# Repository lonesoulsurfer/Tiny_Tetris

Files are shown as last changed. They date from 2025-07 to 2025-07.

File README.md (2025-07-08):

# Tiny_Tetris



YouTube Vid
https://www.youtube.com/watch?v=bwNg85aia90&feature=youtu.be

Ever wanted a pocket sized Tetris that you could whip out anytime you wanted?  Well you are in luck.  This build usues an ATTiny85 to run Tetris on an OLED SDD1306 screen.  It's tiny but definitely usable and did I mention it's ridiculously fun to play!

You'll find all of the files in this repository to build your own

I've also done a step by step guide on Instructables in case you are new to this type of thing.  It's takes you through the build and programming the ATTiny85

Instructables - How to program an ATtiny85 & ATtiny13a
https://www.instructables.com/Tiny-Tetris-ATtiny85-Project/

Instructables - ATtiny 85/13 Programmer
https://www.instructables.com/Programmer-for-ATtiny-85/

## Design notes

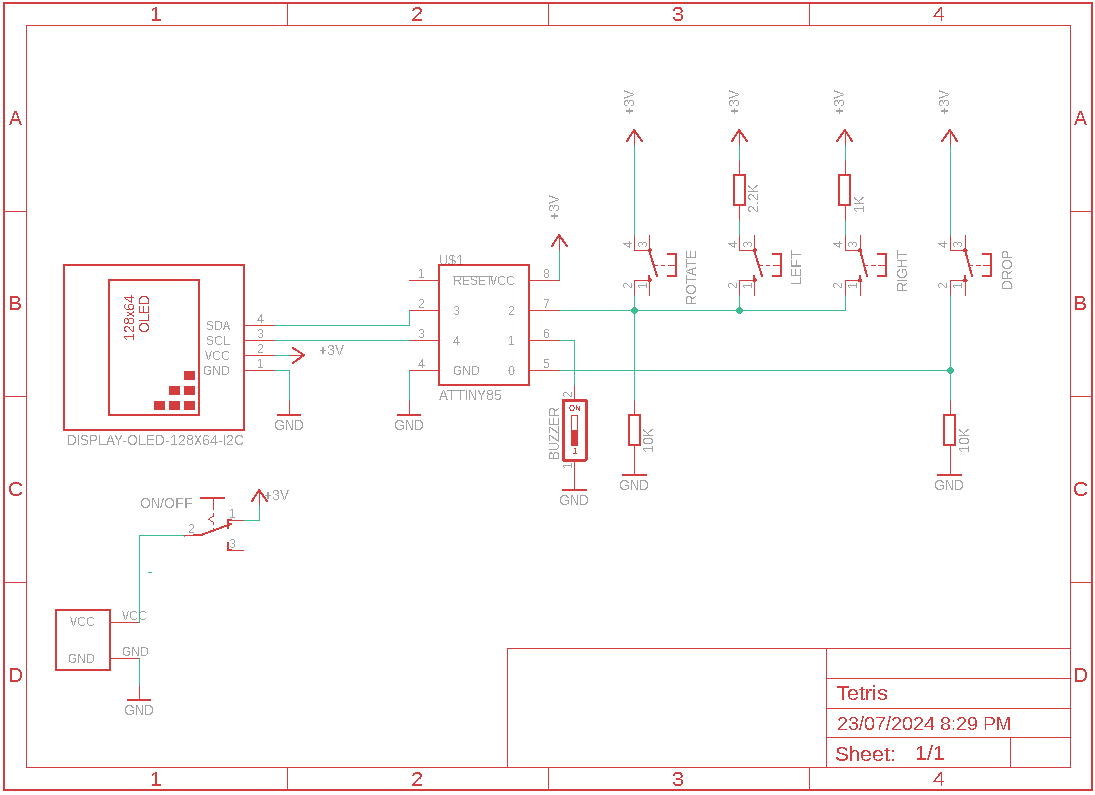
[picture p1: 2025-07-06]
Schematic.png

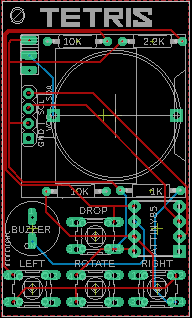
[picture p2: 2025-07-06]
Board.png

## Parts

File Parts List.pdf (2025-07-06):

Part Type Value Qty Link | Image

ATtiny85 IC 1 Link (https://www.aliexpress.com/w/wholesale-attiny-85.html?spm=a2g0o.home.search.0)

Buzzer Passive 1 Link (https://vi.aliexpress.com/item/1005001482792890.html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)

OLED Screen SSD1306 1 Link (https://www.aliexpress.com/w/wholesale-ssd1306.html)

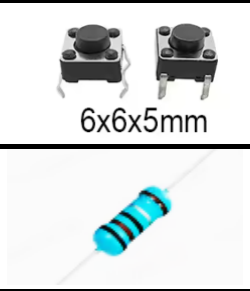
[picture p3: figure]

Mometary Switch Tactile (5mm) 4 Link (https://vi.aliexpress.com/w/wholesale-momentary-tactile-switch.html?spm=a2g0o.productlist.search.0)

10K 2 Resistors Metal Film 1% 1K 1 Link (https://vi.aliexpress.com/w/wholesale-metal-film-1%25-resistor.html?spm=a2g0o.productlist.search.0) 2.2K 1

Battery Holder CR2032 1 Link (https://vi.aliexpress.com/item/4001240194584.html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)

Battery CR2032 Link (https://vi.aliexpress.com/w/wholesale-cr2032-battery.html?spm=a2g0o.productlist.search.0)

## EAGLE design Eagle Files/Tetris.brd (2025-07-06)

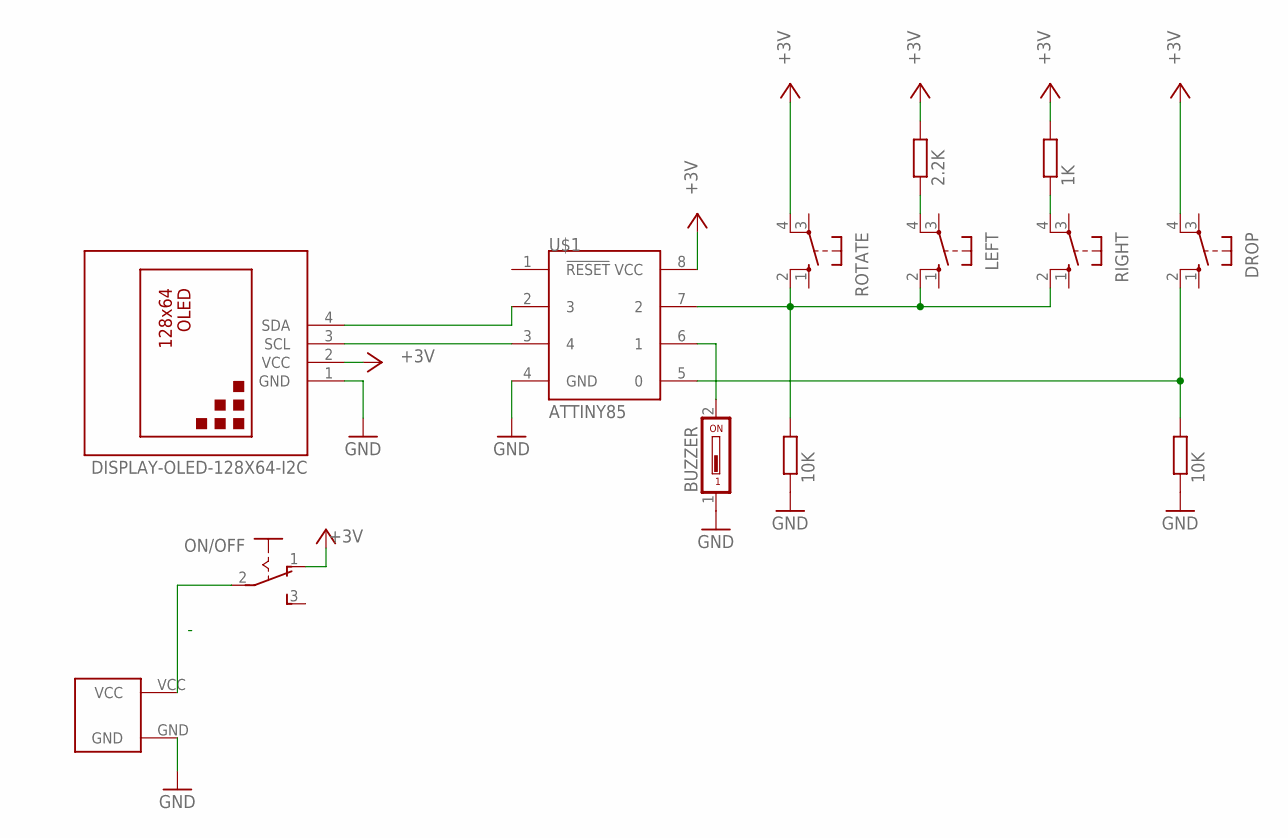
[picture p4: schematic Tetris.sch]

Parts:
BUZZER: DS01; DS-01
DROP: 10-XX; B3F-10XX
LEFT: 10-XX; B3F-10XX
ON/OFF: M251
R1: 2.2K; 0207/10
R2, R4: 10K; 0207/10
R3: 1K; 0207/10
RIGHT: 10-XX; B3F-10XX
ROTATE: 10-XX; B3F-10XX
U$1: ATTINY85; 8P3
U$2: DISPLAY-OLED-128X64-I2C
U$5: CR2032; CR2032-20MM

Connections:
+3V3: DROP.4 (P1), ON/OFF.1 (O), R1.2, R3.2, ROTATE.4 (P1), U$1.8 (VCC), U$2.2 (VCC)
GND: BUZZER.1, R2.1, R4.1, U$1.4 (GND), U$2.1 (GND), U$5.GND
unnamed: U$1.3 (4), U$2.3 (SCL)
unnamed: U$1.2 (3), U$2.4 (SDA)
unnamed: LEFT.4 (P1), R1.1
unnamed: DROP.2 (S1), R2.2, U$1.5 (0)
unnamed: BUZZER.2, U$1.6 (1)
unnamed: R3.1, RIGHT.4 (P1)
unnamed: LEFT.2 (S1), R4.2, RIGHT.2 (S1), ROTATE.2 (S1), U$1.7 (2)
unnamed: ON/OFF.2, U$5.VCC

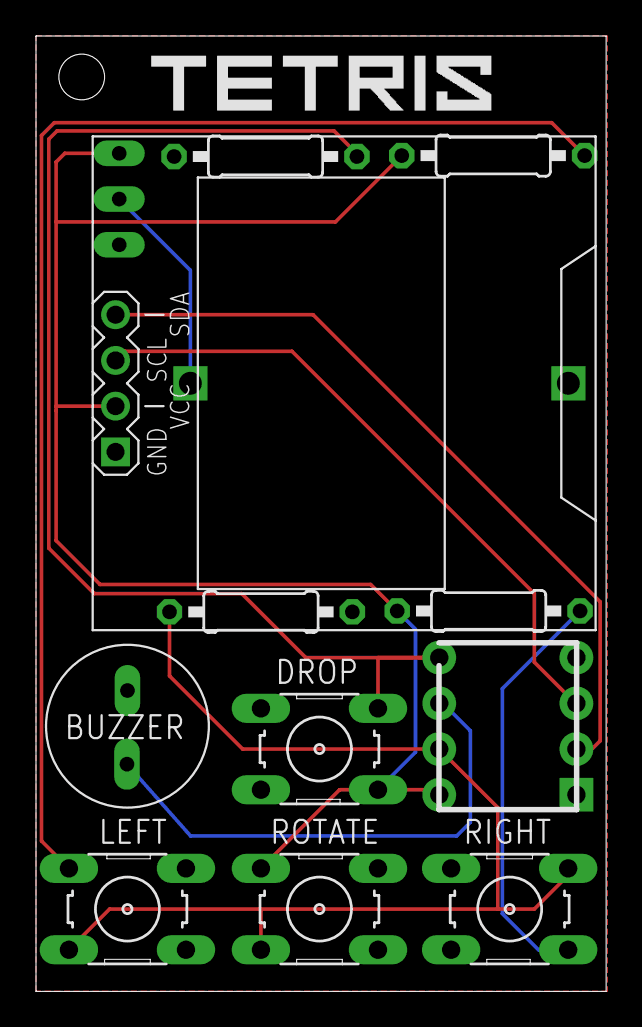
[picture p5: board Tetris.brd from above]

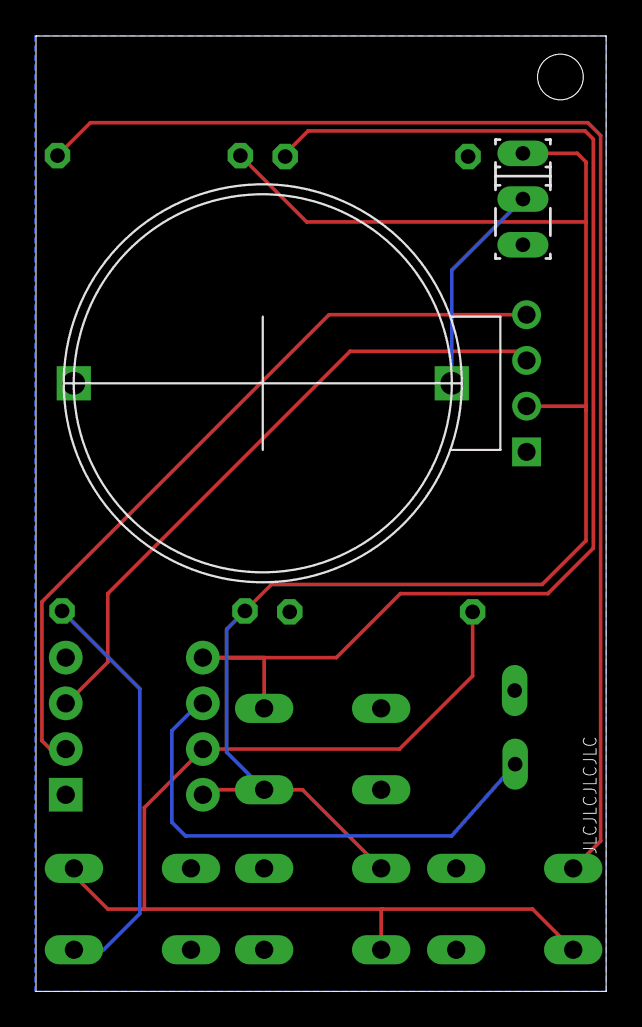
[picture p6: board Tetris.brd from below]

Board: 2 copper layers, 31.7 x 53.1 mm, 13 parts (2 on the bottom side), 10 nets.

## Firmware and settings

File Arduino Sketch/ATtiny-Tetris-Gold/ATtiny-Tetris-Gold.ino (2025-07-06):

/*
   ATtiny Tetris Gold - Multi Button
                 music, additional sounds and improvements

   ===========================================================================
   Andy Jackson, Anthony Russell, Tobozo, Neven Boyanov, Jarosław Mazurkiewicz
   2015 / 2016 / 2017 / 2019

   Before the game starts:
   ===========================================================================
   Hold "DROP" BUTTON - Turns 'ghost' piece on and off
   Hold "DROP" and "ROTATE" together - Turns 'challenge mode' on and off

   The code that does not fall under the licenses of sources listed below
   can be used non-commercially with or without attribution.
   This software is supplied without warranty of any kind.

   For more information please visit:
   https://jm.iq.pl/tetris

*/

// The custom font file is the only additional file you should need to compile this game
#include "font8x8AJ.h"

// Standard Arduino headers
#include <EEPROM.h> 
#include <avr/pgmspace.h>
#include <avr/sleep.h>
#include <avr/interrupt.h> // needed for the additional interrupt

// Mode settings for functions with multiple purposes
#define NORMAL 0
#define GHOST 1
#define FULL 0
#define PARTIAL 1
#define DRAW 0
#define ERASE 1

// The horizontal width of the playing area
#define HORIZ 10
// The vertical visible space of the playing area
#define VERTDRAW 19
// The size of the array of blocks (some are outside visible area to allow them to drop in from off screen)
#define VERTMAX 24

// The horizontal position where pieces begin
#define STARTX 3
// The vertical position where pieces begin
#define STARTY 19
// What level does the game start on
#define STARTLEVEL 1
// The multiplying factor that sets how the speed scales with level (one level increment for every row cleared)
#define LEVELFACTOR 4
// The number of milliseconds before each drop (baseline)
#define DROPDELAY 600

#define DIGITAL_WRITE_HIGH(PORT) PORTB |= (1 << PORT)
#define DIGITAL_WRITE_LOW(PORT) PORTB &= ~(1 << PORT)

// Routines to set and clear bits (used in the sleep code)
#define cbi(sfr, bit) (_SFR_BYTE(sfr) &= ~_BV(bit))
#define sbi(sfr, bit) (_SFR_BYTE(sfr) |= _BV(bit))

// Defines for OLED output
#define SSD1306XLED_H
#define SSD1306_SCL   PORTB4  // SCL, Pin 4 on SSD1306 Board - for webbogles board
#define SSD1306_SDA   PORTB3  // SDA, Pin 3 on SSD1306 Board - for webbogles board
#define SSD1306_SA    0x78  // Slave address

// The bitmaps for the little images of next block
static const byte miniBlock[][4] PROGMEM = {
    {0x77, 0x77, 0x00, 0x00}, 
    {0x70, 0x77, 0x70, 0x00}, 
    {0x70, 0x00, 0x70, 0x77}, 
    {0x70, 0x07, 0x70, 0x07}, 
    {0x70, 0x07, 0x00, 0xEE}, 
    {0x70, 0x77, 0x00, 0x0E}, 
    {0x70, 0x07, 0xEE, 0x00}
    };

// The bitmaps for the main blocks
static const int blocks[7] PROGMEM = {
  0x4444, 0x44C0, 
  0x4460, 0x0660, 
  0x06C0, 0x0E40, 
  0x0C60};

// The bitmaps for blocks on the screen
static const byte  blockout[16] PROGMEM = {
  0xF8, 0x00, 0x3E, 0x80, 
  0x0F, 0xE0, 0x03, 0xF8, 
  0x3E, 0x80, 0x0F, 0xE0, 
  0x03, 0xF8, 0x3E, 0x00};

// The bitmaps for ghost blocks on the screen
static const byte  ghostout[16] PROGMEM = {
  0x88, 0x00, 0x22, 0x80, 
  0x08, 0x20, 0x02, 0x88, 
  0x22, 0x80, 0x08, 0x20, 
  0x02, 0x88, 0x22, 0x00};

// Decode lookup to translate block positions to the 8 columns on the screen
static const byte startDecode[11] PROGMEM = {0,1,1,2,3,4,4,5,6,7,8};
static const byte endDecode[11] PROGMEM =   {1,2,3,3,4,5,6,6,7,8,8};

// The  logo on the opening screen - adapted from the original by Tobozo https://github.com/tobozo
const byte brickLogo[] PROGMEM= {
  0x01, 0x01, 0x01, 0x01, 0x81, 0x81, 0xC1, 0xE1, 
  0xF1, 0xF1, 0x01, 0x11, 0xF1, 0xF1, 0xE1, 0xC1, 
  0xC1, 0x81, 0x81, 0x01, 0x01, 0x01, 0x01, 0x01, 
  0x01, 0x01, 0x01, 0x01, 0x01, 0x01, 0x01, 0x01, 
  0x01, 0x01, 0x01, 0x01, 0xFC, 0xFC, 0xFE, 0xFF, 
  0xFF, 0xFF, 0xFF, 0xFF, 0xFF, 0xFF, 0xFF, 0x00, 
  0xFF, 0xFF, 0xFF, 0xFF, 0xFF, 0xFF, 0xFF, 0xFF, 
  0xFF, 0xFE, 0xF8, 0x00, 0x00, 0x00, 0x00, 0x00, 
  0x00, 0x00, 0x00, 0x00, 0x00, 0x00, 0x00, 0x00,
  0xFF, 0xFF, 0x7F, 0x3F, 0xBF, 0x9F, 0xCF, 0xEF, 
  0xE7, 0xF7, 0xFB, 0xE0, 0x01, 0xFB, 0xF3, 0xF7, 
  0xE7, 0xEF, 0xCF, 0xDF, 0xDF, 0xBF, 0xBF, 0x30, 
  0x00, 0x00, 0x00, 0x00, 0x00, 0x00, 0x00, 0x00, 
  0x00, 0x00, 0x00, 0x00, 0x00, 0xFE, 0xFF, 0xFF, 
  0xFF, 0xFF, 0xFF, 0xFF, 0xFF, 0xFF, 0xFF, 0xFF, 
  0x00, 0x3F, 0xFF, 0xFF, 0xFF, 0xFF, 0xFF, 0xFF, 
  0xFF, 0xFF, 0xFF, 0xFF, 0xE0, 0x06, 0xFE, 0xFC, 
  0xFC, 0xFC, 0xF8, 0xF8, 0xF0, 0xF0, 0xE0, 0x00, 
  0x00, 0xFF, 0xFF, 0x7F, 0x7F, 0x3F, 0xBF, 0x9F, 
  0xDF, 0xCF, 0xEF, 0xEF, 0xE4, 0x00, 0xF7, 0xE7, 
  0xEF, 0xEF, 0xCF, 0xDF, 0xDF, 0x9F, 0xBF, 0xBF, 
  0x3F, 0x00, 0x07, 0x7F, 0xFF, 0xFF, 0xFF, 0xFF,
  0xFF, 0xFF, 0xFF, 0xF0, 0x00, 0xFC, 0xFE, 0xFE, 
  0xFF, 0xFF, 0xFF, 0xFF, 0xFF, 0xFF, 0xFF, 0xFF, 
  0xFF, 0x80, 0x07, 0xFF, 0xFF, 0xFF, 0xFF, 0xFF, 
  0xFF, 0xFF, 0xFF, 0xFF, 0xFF, 0xFF, 0xC0, 0x0E, 
  0x3E, 0x1E, 0x1C, 0x1D, 0x0D, 0x09, 0x03, 0x03, 
  0x00, 0x07, 0xFF, 0xFF, 0xFF, 0xFF, 0xFF, 0xFF, 
  0xFF, 0xFF, 0xFF, 0x7F, 0x7F, 0x3F, 0x00, 0x3F, 
  0x3F, 0x7F, 0x7F, 0x7F, 0x7F, 0x7F, 0xFF, 0xFF, 
  0xFF, 0xFF, 0xFF, 0x80, 0x00, 0x00, 0x00, 0x00, 
  0x00, 0x00, 0x00, 0x00, 0x80, 0x80, 0x83, 0x83, 
  0x83, 0x89, 0x8D, 0x8D, 0x8C, 0x8E, 0x8E, 0x8E, 
  0x8F, 0x8F, 0x9F, 0x8F, 0x8F, 0x8F, 0x8F, 0x87, 
  0x86, 0x86, 0x82, 0x82, 0x82, 0x80, 0x80, 0x80,
  0x80, 0x80, 0x80, 0x80, 0x80, 0x80, 0x80, 0x80};

const int music[][2] PROGMEM = {
  {  752, 828 }, { 1004, 384 }, {  948, 384 }, {  845, 384 }, {  752,  190 },
  {  845, 190 }, {  948, 384 }, { 1004, 384 }, { 1127, 808 }, {    0,   40 },
  { 1127, 364 }, {  948, 384 }, {  752, 828 }, {  845, 384 }, {  948,  384 },
  { 1004, 808 }, {    0,  40 }, { 1004, 380 }, {  948, 384 }, {  845,  828 },
  {  752, 828 }, {  948, 828 }, { 1127, 768 }, {    0,  40 }, { 1127, 1676 },

  {  845, 798 }, {    0,  40 }, {  845, 354 }, {  710, 384 }, {  562,  828 },
  {  632, 384 }, {  710, 384 }, {  752, 808 }, {    0,  40 }, {  752,  364 },
  {  948, 384 }, {  752, 828 }, {  845, 384 }, {  948, 384 }, { 1004,  808 },
  {    0,  40 }, { 1004, 380 }, {  948, 384 }, {  845, 828 }, {  752,  828 },
  {  948, 828 }, { 1127, 748 }, {    0,  14 }, {    0,  26 }, { 1127, 1696 }};

// Function prototypes - generic ones I use in all games
void beep(int,int);

// Function prototypes - screen control modified from https://bitbucket.org/tinusaur/ssd1306xled
void ssd1306_init(void);
void ssd1306_xfer_start(void);
void ssd1306_xfer_stop(void);
void ssd1306_send_byte(uint8_t byte);
void ssd1306_send_command(uint8_t command);
void ssd1306_send_data_start(void);
void ssd1306_send_data_stop(void);
void ssd1306_setpos(uint8_t x, uint8_t y);
void ssd1306_fillscreen(uint8_t fill_Data);
void ssd1306_char_f8x8(uint8_t x, uint8_t y, const char ch[]);

// Function prototypes - tetris-specific
void playTetris(void);
void handleInput(void);

void drawScreen(int startCol, int endCol, int startRow, int endRow, byte mode);
void drawScreenBorder(void);

byte readBlockArray(byte x, byte y);
void writeblockArray(byte x, byte y, bool value);
byte readGhostArray(byte x, byte y);
void writeGhostArray(byte x, byte y, bool value);
void fillGrid(byte value, bool mode);

void rotatePiece(void);
bool movePieceDown(void);
void movePieceLeft(void);
void movePieceRight(void);
byte checkCollision(void);

bool createGhost(void);
void drawGhost(byte action);
void loadPiece(byte pieceNumber, byte row, byte column);
void drawPiece(byte action);
void setNextBlock(byte pieceNumber);

// Variables 
struct pieceSpace {
  byte blocks[4][4];
  int row;
  int column;
};

pieceSpace currentPiece = {0};  // The piece in play
pieceSpace oldPiece = {0};      // Buffer to hold the current piece whilst its manipulated
pieceSpace ghostPiece = {0};    // Current ghost piece

unsigned long moveTime = 0;     // Baseline time for current move
unsigned long keyTime = 0;      // Baseline time for current keypress

byte keyLock = 0;               // Holds the mode of the last keypress (for debounce and stuff)

byte nextBlockBuffer[8][2];     // The little image of the next block 
byte nextPiece = 0;             // The identity of the next piece
byte blockArray[HORIZ][3];      // The byte-array of blocks
byte ghostArray[HORIZ][3];      // The byte-array of ghost pieces
bool stopAnimate;               // True when the game is running

int lastGhostRow = 0;           // Buffer to hold previous ghost position - for accurate drawing
int score = 0;                  // Score buffer
int topScore = 0;               // High score buffer

bool challengeMode = 0;         // Is the system in "Hard" mode?
bool ghost = 0;                 // Is the ghost active?

int level = 0;                  // Current level (increments once per cleared line)



/* 
 * Interrupt handlers - to make sure every button press is caught promptly! 
 */

// PB0 pin button interrupt
ISR(PCINT0_vect) { 
  if (keyLock == 0) {
    keyLock = 4; // Nothing complicated to do here - this is picked up in the handleInput() function 
    }
}

/*
 * This interrupt routine relies on having three buttons wired to pin 7 of the Attiny85 - all with a single pull-down resistor (10k) and 
 *  - One that pulls-up to +Vcc (giving an analog reading of 1023)
 *  - One that pulls-up via a 1k resistor (analog reading somewhere around 930ish)
 *  - One that pulls-up via a 2.2 resistor (analog reading around 840)
 * 
 * The key point is that all three buttons provide a voltage that sends the pin to logic-high, thus triggering the interrupt
 * (therefore you could add more buttons, as long as the voltage is always above the threshold that the Attiny85 would class
 * as logic-high). 
 * 
 * In practice, this technique requires a reasonably well made and well insulated board - adding moisture to to board (via damp
 * hands for example) would likely throw the voltages out enough that this technique would become unreliable.
 * 
 */
 // PB2 pin button interrupt
void playerIncTetris() { 
  if (keyLock == 0) {
    int ic = analogRead(1);
    if (ic > 800 && ic < 855) {
      keyLock = 1;
    } else if (ic > 855 && ic < 970) {
      keyLock = 2;
    } else if (ic > 970 && ic < 1025) {
      keyLock = 3;
    }
  }
}

// Beep function - originally from the games by www.webboggles.com 
void beep(int bCount,int bDelay){
 for (int i = 0; i<=bCount; i++){digitalWrite(1,HIGH);for(int i2=0; i2<bDelay; i2++){__asm__("nop\n\t");}digitalWrite(1,LOW);for(int i2=0; i2<bDelay; i2++){__asm__("nop\n\t");}}
}

// SSD1306 screen drawing functions - adapted from https://bitbucket.org/tinusaur/ssd1306xled
void ssd1306_char_f8x8(uint8_t x, uint8_t y, const char ch[]) {
  uint8_t c, i, j = 0;

  while (ch[j] != '\0')
  {
    // These corrections allow for the fact that I've stripped out sections of the ASCII map from the font file
    // If code space allows, then you could add some or all of them back in, but then you'd need to remove some or all of these lines.
    c = ch[j] - 32; // to space
    if (c > 0) c = c - 12; // to dash
    if (c > 15) c = c - 7; 
    if (c > 40) c = c - 6;

    ssd1306_setpos(y, x);
    ssd1306_send_data_start();
    for (byte lxn = 0; lxn < 8; lxn++) {    
      ssd1306_send_byte(pgm_read_byte(&font[c][7-lxn]));      
      }
    ssd1306_send_data_stop();
    x+= 1;
    j++;
  }
}

void ssd1306_init(void) {
  DDRB |= (1 << SSD1306_SDA); // Set port as output
  DDRB |= (1 << SSD1306_SCL); // Set port as output

  ssd1306_send_command(0xAE); // display off
  ssd1306_send_command(0x00); // Set Memory Addressing Mode
  ssd1306_send_command(0x10); // 00,Horizontal Addressing Mode;01,VERTDRAWical Addressing Mode;10,Page Addressing Mode (RESET);11,Invalid
  ssd1306_send_command(0x40); // Set Page Start Address for Page Addressing Mode,0-7
  ssd1306_send_command(0x81); // Set COM Output Scan Direction
  ssd1306_send_command(0xCF); // ---set low column address
  ssd1306_send_command(0xA1); // ---set high column address
  ssd1306_send_command(0xC8); // --set start line address
  ssd1306_send_command(0xA6); // --set contrast control register
  ssd1306_send_command(0xA8);
  ssd1306_send_command(0x3F); // --set segment re-map 0 to 127
  ssd1306_send_command(0xD3); // --set normal display
  ssd1306_send_command(0x00); // --set multiplex ratio(1 to 64)
  ssd1306_send_command(0xD5); //
  ssd1306_send_command(0x80); // 0xa4,Output follows RAM content;0xa5,Output ignores RAM content
  ssd1306_send_command(0xD9); // -set display offset
  ssd1306_send_command(0xF1); // -not offset
  ssd1306_send_command(0xDA); // --set display clock divide ratio/oscillator frequency
  ssd1306_send_command(0x12); // --set divide ratio
  ssd1306_send_command(0xDB); // --set pre-charge period
  ssd1306_send_command(0x40); //
  ssd1306_send_command(0x20); // --set com pins hardware configuration
  ssd1306_send_command(0x02);
  ssd1306_send_command(0x8D); // --set vcomh
  ssd1306_send_command(0x14); // 0x20,0.77xVcc
  ssd1306_send_command(0xA4); // --set DC-DC enable
  ssd1306_send_command(0xA6); //
  ssd1306_send_command(0xAF); // --turn on oled panel
}

void ssd1306_xfer_start(void) {
  DIGITAL_WRITE_HIGH(SSD1306_SCL);  // Set to HIGH
  DIGITAL_WRITE_HIGH(SSD1306_SDA);  // Set to HIGH
  DIGITAL_WRITE_LOW(SSD1306_SDA);   // Set to LOW
  DIGITAL_WRITE_LOW(SSD1306_SCL);   // Set to LOW
}

void ssd1306_xfer_stop(void) {
  DIGITAL_WRITE_LOW(SSD1306_SCL);   // Set to LOW
  DIGITAL_WRITE_LOW(SSD1306_SDA);   // Set to LOW
  DIGITAL_WRITE_HIGH(SSD1306_SCL);  // Set to HIGH
  DIGITAL_WRITE_HIGH(SSD1306_SDA);  // Set to HIGH
}
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
void loop() {
  ssd1306_init();
  ssd1306_fillscreen(0x00);

  drawScreenBorder();
  ssd1306_char_f8x8(1, 64,"TETRIS");
  ssd1306_char_f8x8(1, 48, "Attiny");
  ssd1306_char_f8x8(1, 40, "Arcade");
  drawScreenBorder();

  for (byte lxn = 0; lxn < 8; lxn++) {
    ssd1306_setpos(78, lxn); 
    ssd1306_send_data_start(); 
    for (byte lxn2 = 0; lxn2 < 36; lxn2++) {
      ssd1306_send_byte(pgm_read_byte(&brickLogo[36*lxn+lxn2]));  
    }
    ssd1306_send_data_stop(); 
  }

  long startT = millis();
  long nowT =0;
  boolean sChange = 0;
  while(digitalRead(0) == HIGH) {
    nowT = millis();
    if (nowT - startT > 2000) {
      sChange = 1;
      beep(20, 956);
      if (digitalRead(2) == HIGH) {
        ssd1306_char_f8x8(2, 8, "MODE"); 
        if (challengeMode == 0) { 
          challengeMode = 1; 
          ssd1306_char_f8x8(2, 16, "HARD"); 
        } else { 
          challengeMode = 0; 
          ssd1306_char_f8x8(1, 16, "NORMAL"); 
        }
      } else {
        ssd1306_char_f8x8(1, 16, "GHOST"); 
        if (ghost == 0) { 
          ghost = 1; 
          ssd1306_char_f8x8(2, 8, "ON"); 
        } else { 
          ghost = 0; 
          ssd1306_char_f8x8(2, 8, "OFF"); 
        }    
      }
      break;
    }
    if (sChange == 1) break;
  }  
  while(digitalRead(0) == HIGH);
  
  if (sChange == 0) {
    ssd1306_char_f8x8(2, 21, "GOLD"); 
    // playing the Tetris Theme
    uint8_t sng = (ghost == 1) ? 50 : 25;
    for (uint8_t i = 0; i < sng; i++) {
      soundPlay(pgm_read_word_near(&(music[i][0])), pgm_read_word_near(&(music[i][1])));
    }
    ssd1306_fillscreen(0x00);
    playTetris();
  }
  delay(1000);
  system_sleep();
}

/*
 *  These functional allow optimal storing of the array of Tetris and Ghost blocks by using a 10x3 array of bytes and extracting the relevant bit through shifting and masking
 */

byte readBlockArray(byte x, byte y) {
    if (y < 8) {
      return ((blockArray[x][0] & B00000001 << y) >> y);
    } else if (y > 15) {
      return ((blockArray[x][2] & B00000001 << y-15) >> y-15);
    } else {
      return ((blockArray[x][1] & B00000001 << y-8) >> y-8);
    }   
}

void writeblockArray(byte x, byte y, bool value) {
    byte arr = 0;
    if (y<8) {
      // do nothing 
    } else if (y > 15) {
      arr = 2;
      y-=15;
    } else  {
      arr = 1;
      y-=8;
    }  
    if (value == 1) blockArray[x][arr] |= B00000001 << y; else blockArray[x][arr] &= (B11111110 << y) | (B01111111 >> 7-y);
}

byte readGhostArray(byte x, byte y) {
    if (y < 8) {
      return ((ghostArray[x][0] & B00000001 << y) >> y);
    } else if (y > 15) {
      return ((ghostArray[x][2] & B00000001 << y-15) >> y-15);
    } else {
      return ((ghostArray[x][1] & B00000001 << y-8) >> y-8);
    }   
}

void writeGhostArray(byte x, byte y, bool value) {
    byte arr = 0;
    if (y<8) {
      // do nothing
    } else if (y > 15) {
      arr = 2;
      y-=15;
    } else  {
      arr = 1;
      y-=8;
    }  
    if (value == 1) ghostArray[x][arr] |= B00000001 << y; else ghostArray[x][arr] &= (B11111110 << y) | (B01111111 >> 7-y);
}

void fillGrid(byte value, bool mode) {
  for (char r = 0; r < VERTMAX; r++) {
    for (char c = 0; c < HORIZ; c++) {
      if (mode == GHOST) writeGhostArray(c,r, value); else writeblockArray(c,r, value);
    }
  }
}

void rotatePiece(void) {
  byte blocks[4][4];

  memcpy(oldPiece.blocks, currentPiece.blocks, 16);
  oldPiece.row = currentPiece.row;
  oldPiece.column = currentPiece.column;

  for (byte i = 0; i < 4; ++i) {
    for (byte j = 0; j < 4; ++j) {
      blocks[j][i] = currentPiece.blocks[4 - i - 1][j];
    }
  }
  oldPiece = currentPiece;
  memcpy(currentPiece.blocks, blocks, 16);
  if (checkCollision()) currentPiece = oldPiece; else {
    drawGhost(ERASE);
    if (createGhost()) drawGhost(DRAW);
    }
}

bool movePieceDown(void) {
  int rndPiece = 0;

  memcpy(oldPiece.blocks, currentPiece.blocks, 16);
  oldPiece.row = currentPiece.row;
  oldPiece.column = currentPiece.column;

  currentPiece.row--;

  //check collision
  if (checkCollision()) {
    currentPiece.row = oldPiece.row;
    drawPiece(DRAW);
    byte totalRows = 0;
    
    for (byte row = 0; row < VERTMAX; row++) { // scan the whole block (it's quick - there's no drawing to do)
      bool rowFull = 1;
      for (byte col = 0; col < HORIZ; col++) { // scan across this row - every column
        if (readBlockArray(col,row) == 0) rowFull = 0; // if we hit any blank spaces, the row's not full
      }
      if (rowFull) {
        totalRows++;
        for (int i = 800; i>200; i = i - 200) beep(30,i); // happy sound
        for (byte col = 0; col < HORIZ; col++) writeblockArray(col,row,0); // write zeros across this whole row
        drawGameScreen(0,HORIZ-1,row,row+1,PARTIAL); // draw the row we're removing (for animation)
        delay(30); // delay slightly to make the deletion of rows visible
        for (byte dropCol = 0; dropCol < HORIZ; dropCol++) { // for every column
          for (byte dropRow = row; dropRow < VERTMAX-1; dropRow ++) writeblockArray(dropCol,dropRow,readBlockArray(dropCol,dropRow+1)); // drop everything down as many as the row's we've cleared
        }
        row--; // we need to check this row again as it could now have things in it!
      }
    }
    level += totalRows;
    switch (totalRows) {
      case 1:   score += 40; break;
      case 2:   score += 100; break;
      case 3:   score += 300; break;
      case 4:   score += 800; 
    }
    drawGameScreen(0,10, 0,VERTDRAW,FULL); 
    displayScore(score, 0,117,0);
    loadPiece(nextPiece, STARTY, STARTX);
    if (checkCollision()) {
      stopAnimate = true;
    } else {
      loadPiece(nextPiece, STARTY, STARTX);
      drawGhost(ERASE);
      if (createGhost()) drawGhost(DRAW);
    }
    nextPiece = random(1, 8);
    setNextBlock(nextPiece);
  }
  drawGhost(ERASE);
  if (createGhost()) drawGhost(DRAW);
}

void movePieceLeft(void) {
  byte response;
 
  oldPiece = currentPiece;
  currentPiece.column = currentPiece.column - 1;

  response = checkCollision();

  if (checkCollision()) {
    currentPiece = oldPiece; // back to where it was
  } else {
    drawGhost(ERASE);
    if (createGhost()) drawGhost(DRAW);
  }
}

void movePieceRight(void) {
  oldPiece = currentPiece;
  currentPiece.column = currentPiece.column + 1;
  //check collision
  if (checkCollision()) 	{
    currentPiece = oldPiece; // back to where it was
  } else {
    drawGhost(ERASE);
    if (createGhost()) drawGhost(DRAW);
  }
}

byte checkCollision(void) {
  byte pieceRow = 0;
  byte pieceColumn = 0;

  for (int c = currentPiece.column; c < currentPiece.column + 4; c++) {
    for (int r = currentPiece.row; r < currentPiece.row + 4; r++) {
      if (currentPiece.blocks[pieceColumn][pieceRow]) {
        if (c < 0) return 2;
        if (c > 9) return 1;
        if (r < 0) return 1;
        if (c >= 0 && r >= 0 && c < HORIZ && r < VERTMAX) {
          if (readBlockArray(c,r)) {
            return 1; //is it on landed blocks?
          }
        }
      }
      pieceRow++;
    }
    pieceRow = 0;
    pieceColumn++;
  }
  return 0;
}

void handleInput(void) {
  if (digitalRead(0) == LOW && digitalRead(2) == LOW) {
    if (keyLock == 1) {
      drawPiece(ERASE);
      movePieceLeft();
      drawPiece(DRAW);
      drawGameScreen(currentPiece.column, currentPiece.column + 5, currentPiece.row, currentPiece.row+4, PARTIAL);         
    } else if (keyLock == 2) {
      drawPiece(ERASE);
      movePieceRight();
      drawPiece(DRAW);
      drawGameScreen(currentPiece.column-1, currentPiece.column + 4, currentPiece.row, currentPiece.row+4,PARTIAL);         
    } else if (keyLock == 3) {
      drawPiece(ERASE);
      rotatePiece();
      drawPiece(DRAW);
      drawGameScreen(currentPiece.column, currentPiece.column + 4, currentPiece.row, currentPiece.row+4,PARTIAL);         
    }
    keyLock = 0;      
  }

  if (keyLock == 4) {
    while (digitalRead(0) == HIGH) {
      drawPiece(ERASE);
      movePieceDown();
      drawPiece(DRAW);
      drawGameScreen(currentPiece.column, currentPiece.column + 4, currentPiece.row, currentPiece.row+5,PARTIAL);         
      delay(10);
      if (stopAnimate) return;
    }
    keyLock = 0;
  }
  delay(30);
}
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

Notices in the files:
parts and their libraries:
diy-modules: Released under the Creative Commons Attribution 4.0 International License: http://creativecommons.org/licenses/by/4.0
